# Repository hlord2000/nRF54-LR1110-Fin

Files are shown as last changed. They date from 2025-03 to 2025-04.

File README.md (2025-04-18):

# LR1110 Expansion Board for nRF54L15-DK

This expansion board connects the Semtech LR1110 RF transceiver to the Nordic nRF54L15-DK. The board enables LoRa, GNSS, and Wi-Fi scanning capabilities.

<p align="center">
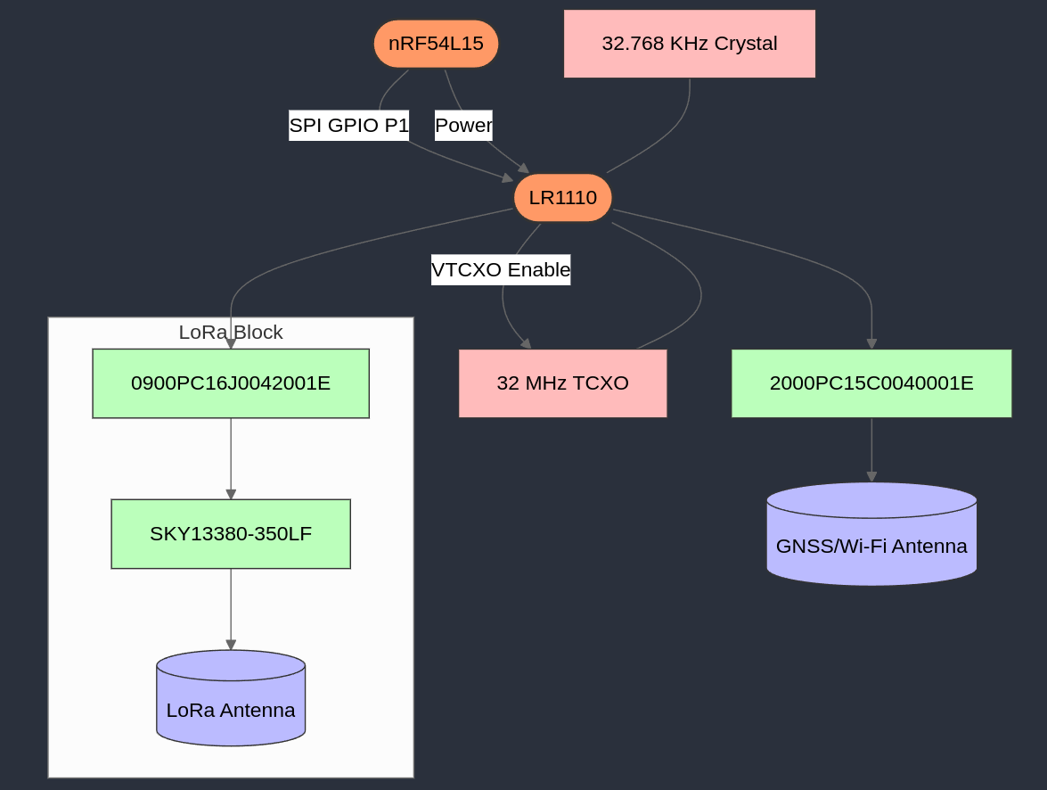
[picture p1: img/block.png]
Block Diagram
  
</p>

## Features

- Supports LoRa connectivity via 0900PC16J0042001E filter and SKY13380-350LF RF switch
- GNSS and Wi-Fi scanning via 2000PC15C0040001E filter (IPDs enable smaller solution size)
- Onboard LNA for non-active GNSS antennas
- 32 MHz TCXO with power-saving VTCXO control from LR1110
- 32.768 KHz crystal for timing reference
- Level shifters to support all possible IO voltages of the nRF54L15
- Compatible with the new nRF54L15 headers

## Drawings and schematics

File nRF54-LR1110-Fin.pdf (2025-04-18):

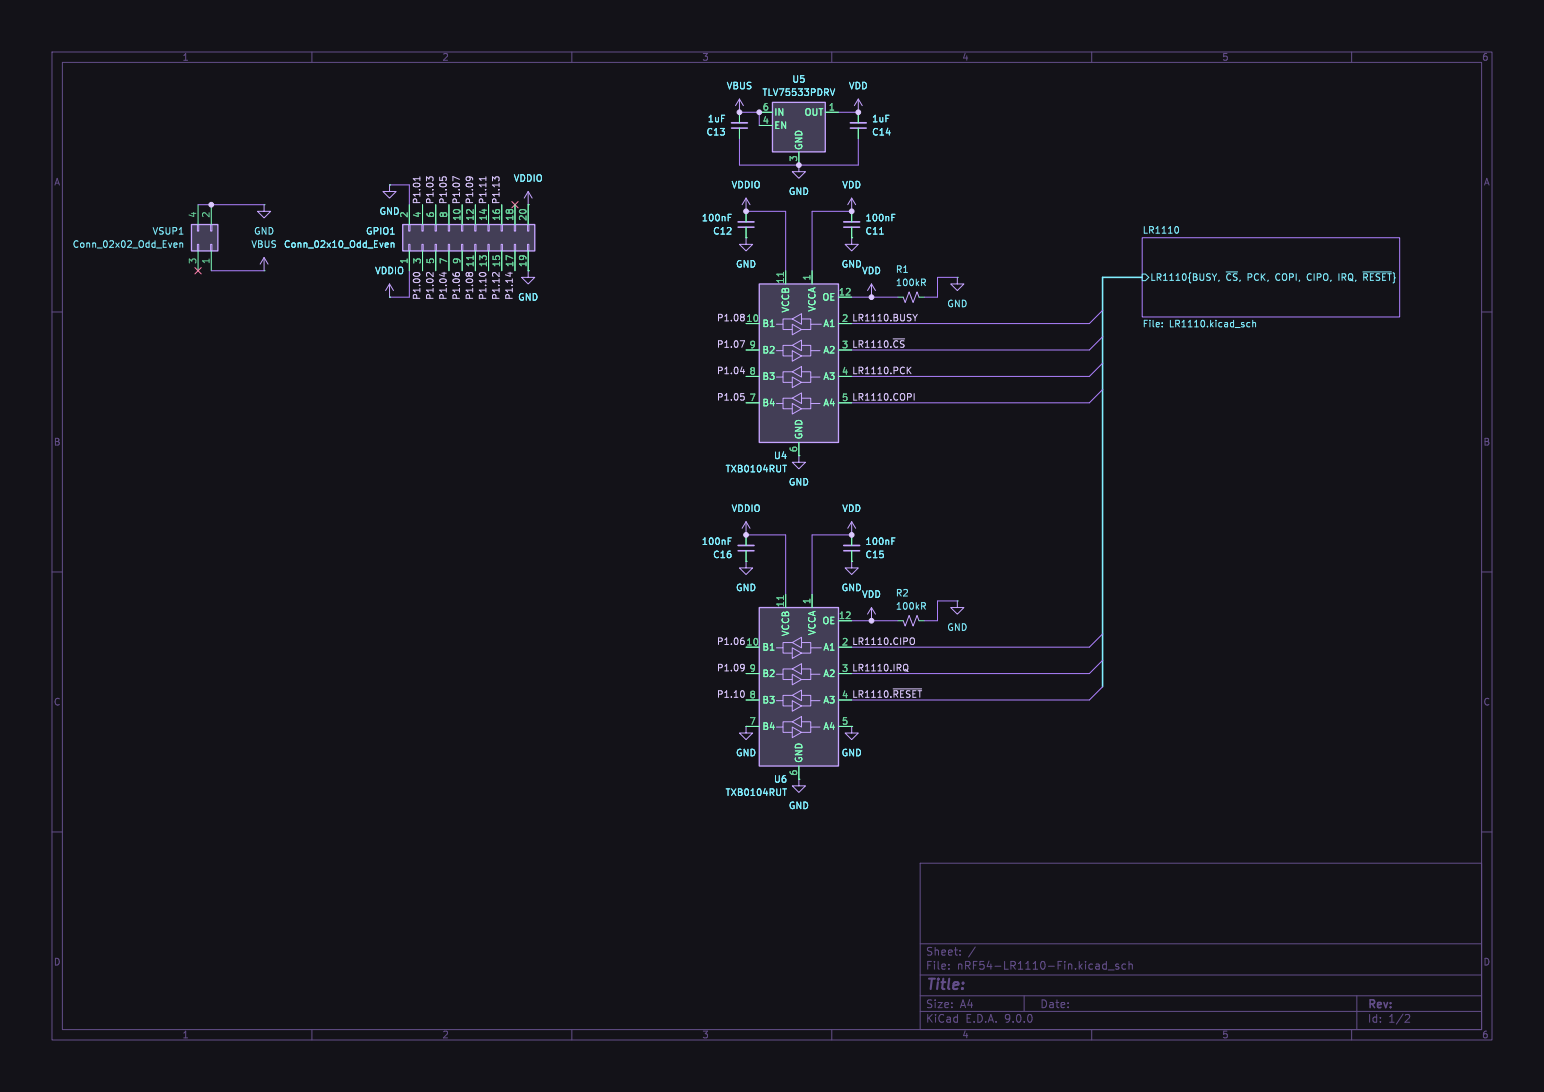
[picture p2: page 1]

Id: 1/2 Title: File: nRF54-LR1110-Fin.kicad_sch Sheet: /

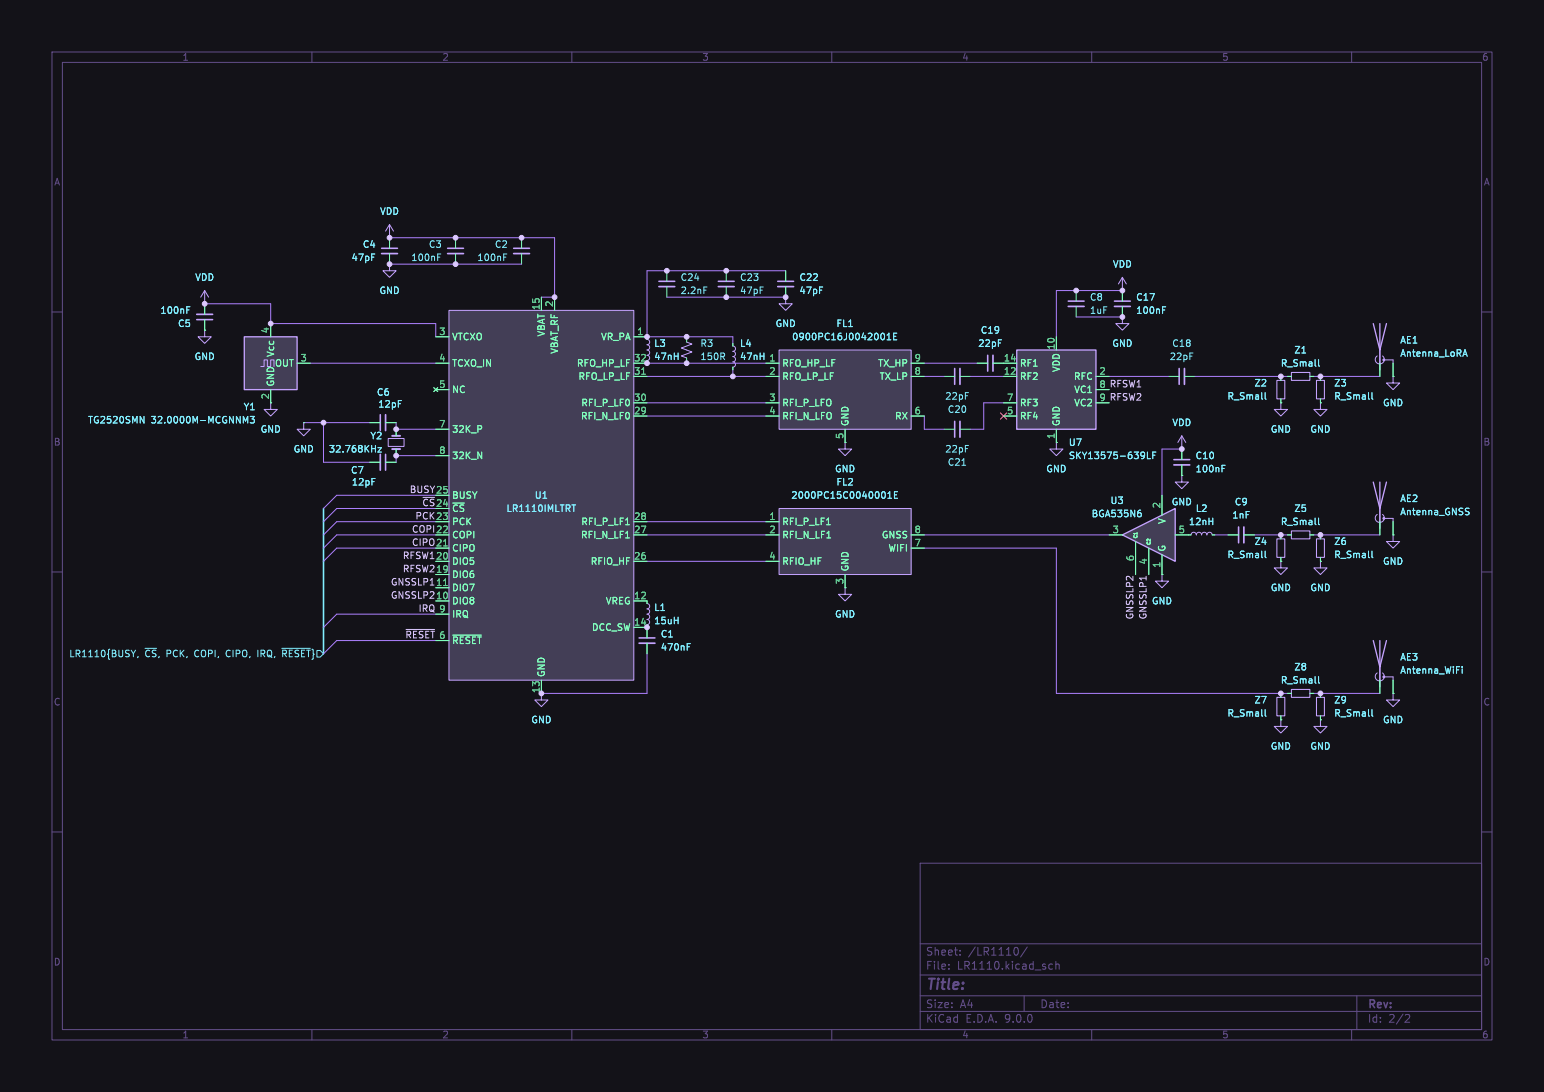
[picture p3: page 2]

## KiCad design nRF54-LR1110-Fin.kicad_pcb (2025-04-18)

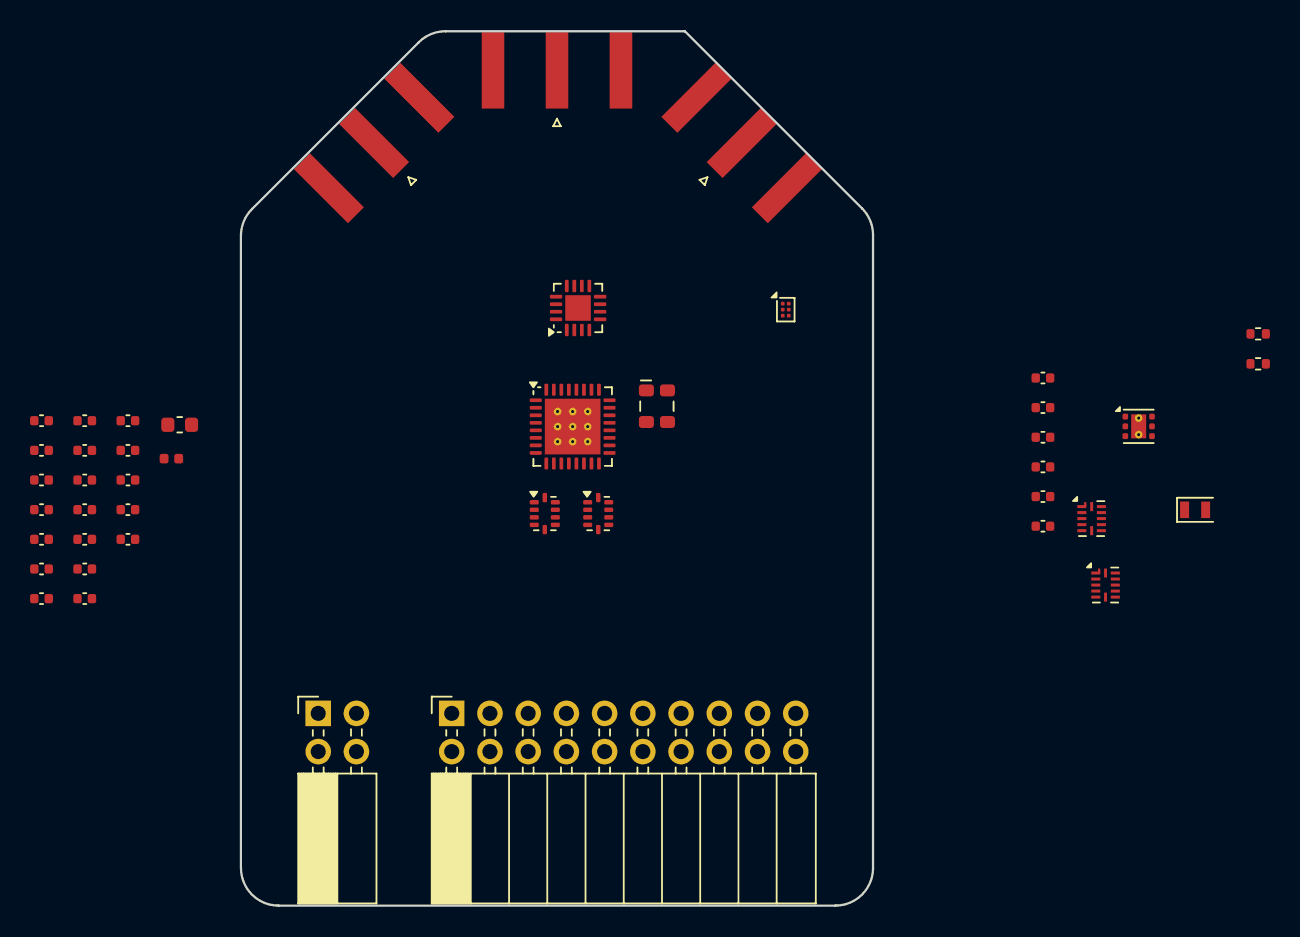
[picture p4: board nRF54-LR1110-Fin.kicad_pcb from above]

Board: 2 copper layers, 42.0 x 58.1 mm, 44 parts (0 on the bottom side), 46 nets, no tracks yet.

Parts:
AE1, AE2, AE3: Antenna_Shield; SMA_Amphenol_132289_EdgeMount
C1: 470nF; C_0402_1005Metric
C2, C3, C5, C8, C10, C11, C12, C15, C16: 100nF; C_0402_1005Metric
C4: 47pF; C_0402_1005Metric
C6, C7: 12pF; C_0402_1005Metric
C9: 1nF; C_0402_1005Metric
C13, C14: 1uF; C_0402_1005Metric
FL1: 0900PC16J0042001E; Balun_Johanson_0900FM15K0039
FL2: 2000PC15C0040001E; Balun_Johanson_0900FM15K0039
GPIO1: Conn_02x10_Odd_Even; PinSocket_2x10_P2.54mm_Horizontal
L1: 15uH; L_0603_1608Metric
L2: 12nH; L_0402_1005Metric
R1, R2: 100kR; R_0402_1005Metric
U1: LR1110IMLTRT; QFN-32-1EP_5x5mm_P0.5mm_EP3.7x3.7mm_ThermalVias
U2: SKY13380-350LF; QFN-16-1EP_3x3mm_P0.5mm_EP1.7x1.7mm
U3: BGA535N6; Infineon_PG-TSNP-6-10_0.7x1.1mm_0.7x1.1mm_P0.4mm
U4, U6: TXB0104RUT; Texas_R-PUQFN-N12
U5: TLV75533PDRV; WSON-6-1EP_2x2mm_P0.65mm_EP1x1.6mm_ThermalVias
VSUP1: Conn_02x02_Odd_Even; PinSocket_2x02_P2.54mm_Horizontal
Y1: TG2520SMN 32.0000M-MCGNNM3; Oscillator_SMD_SeikoEpson_TG2520SMN-xxx-xxxxxx-4Pin_2.5x2.0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
Y2: 32.768KHz; Crystal_SMD_2012-2Pin_2.0x1.2mm
Z1, Z2, Z3, Z4, Z5, Z6, Z7, Z8, Z9: R_Small; C_0402_1005Metric

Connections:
/BUSY: U1.25 (BUSY), U4.2 (A1)
/CIPO: U1.21 (CIPO), U6.2 (A1)
/COPI: U1.22 (COPI), U4.5 (A4)
/GNSSLP1: U1.11 (DIO7), U3.4 (C2)
/GNSSLP2: U1.10 (DIO8), U3.6 (C1)
/IRQ: U1.9 (IRQ), U6.3 (A2)
/P1.04: GPIO1.7, U4.8 (B3)
/P1.05: GPIO1.8, U4.7 (B4)
/P1.06: GPIO1.9, U6.10 (B1)
/P1.07: GPIO1.10, U4.9 (B2)
/P1.08: GPIO1.11, U4.10 (B1)
/P1.09: GPIO1.12, U6.9 (B2)
/P1.10: GPIO1.13, U6.8 (B3)
/PCK: U1.23 (PCK), U4.4 (A3)
/RFSW1: U1.20 (DIO5), U2.4 (CTRL1)
/RFSW2: U1.19 (DIO6), U2.3 (CTRL2)
/~CS: U1.24 (~CS), U4.3 (A2)
/~RESET: U1.6 (~RESET), U6.4 (A3)
GND: AE1.2 (Shield), AE2.2 (Shield), AE3.2 (Shield), C1.2, C2.2, C3.2, C4.2, C5.1, C6.1, C7.2, C8.2, C10.2, C11.1, C12.1, C13.1, C14.1, C15.1, C16.1, FL1.5 (GND), FL1.7 (GND), FL1.10 (GND), FL2.3 (GND), FL2.5 (GND), FL2.6 (GND), FL2.9 (GND), FL2.10 (GND), GPIO1.2, GPIO1.19, R1.2, R2.2, U1.13 (GND), U1.33 (EP), U2.1 (GND), U2.5 (GND), U2.7 (GND), U2.9 (GND), U2.10 (GND), U2.12 (GND), U2.14 (GND), U3.1 (G), U4.6 (GND), U5.3 (GND), U5.7 (GND), U6.5 (A4), U6.6 (GND), U6.7 (B4), VSUP1.2, VSUP1.4, Y1.2 (GND), Z2.1, Z3.1, Z4.1, Z6.1, Z7.1, Z9.1
unnamed: AE1.1 (A), Z1.2, Z3.2
unnamed: AE2.1 (A), Z5.2, Z6.2
unnamed: AE3.1 (A), Z8.2, Z9.2
unnamed: C9.1, L2.2
unnamed: C9.2, Z4.2, Z5.1
unnamed: FL1.4 (RFI_N_LFO), U1.29 (RFI_N_LF0)
unnamed: FL1.3 (RFI_P_LFO), U1.30 (RFI_P_LF0)
unnamed: FL1.1 (RFO_HP_LF), U1.32 (RFO_HP_LF)
unnamed: FL1.2 (RFO_LP_LF), U1.31 (RFO_LP_LF)
unnamed: FL1.6 (RX), U2.8 (RF3)
unnamed: FL1.9 (TX_HP), U2.13 (RF1)
unnamed: FL1.8 (TX_LP), U2.15 (RF2)
unnamed: FL2.8 (GNSS), U3.3
unnamed: FL2.4 (RFIO_HF), U1.26 (RFIO_HF)
unnamed: FL2.2 (RFI_N_LF1), U1.27 (RFI_N_LF1)
unnamed: FL2.1 (RFI_P_LF1), U1.28 (RFI_P_LF1)
unnamed: FL2.7 (WIFI), Z7.2, Z8.1
unnamed: L2.1, U3.5
unnamed: C7.1, U1.8 (32K_N), Y2.1
unnamed: C6.2, U1.7 (32K_P), Y2.2
unnamed: C1.1, L1.2, U1.14 (DCC_SW)
unnamed: L1.1, U1.12 (VREG)
unnamed: U1.4 (TCXO_IN), Y1.3 (OUT)
unnamed: U2.11 (ANT), Z1.1, Z2.2
VBUS: C13.2, U5.4 (EN), U5.6 (IN), VSUP1.1
VDD: C2.1, C3.1, C4.1, C5.2, C8.1, C10.1, C11.2, C14.2, C15.2, R1.1, R2.1, U1.2 (VBAT_RF), U1.3 (VTCXO), U1.15 (VBAT), U2.2 (VDD), U3.2 (V), U4.1 (VCCA), U4.12 (OE), U5.1 (OUT), U6.1 (VCCA), U6.12 (OE), Y1.4 (Vcc)
VDDIO: C12.2, C16.2, GPIO1.1, GPIO1.20, U4.11 (VCCB), U6.11 (VCCB)

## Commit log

2025-03-18 Initial commit.
    [nRF54-LR1110-Fin.kicad_pcb, nRF54-LR1110-Fin.kicad_sch]
2025-04-18 schematic: add level shifter, gnss amp
    Adds level shifter to L15-DK, GNSS amplifier, proper handling of RF
    components for LoRA radio, initial board outline.
    [LR1110.kicad_sch, nRF54-LR1110-Fin.kicad_pcb, nRF54-LR1110-Fin.kicad_sch]
